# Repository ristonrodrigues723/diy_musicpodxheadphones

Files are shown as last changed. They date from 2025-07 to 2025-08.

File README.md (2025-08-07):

# diy_musicpod x headphones

DIY MusicPod x Headphones
Project Cost: $110

Hours Spent: 47 

Description:
This is an audiophile-grade music player, custom-designed by me and inspired by the Sony Walkman. I have designed an audiophile-grade MP3 player with a built-in DAC and amplifier, along with supporting headphones. Two people can use this to listen to music at the same time due to the use of dual jacks.

How to Use This Project:
u can Use it to listen to music without the distraction of ads or phone notifications. It's a seamless, audiophile-grade music experience without intrusions. The dual jacks make it easy for two people to plug in different earphones and listen to the same music.

Why did you make this project?-
I wanted an audiophile-grade music experience without the high price tag. Making something of my own was the most logical way to do it, so I designed and built this project.

Sources

onshape link(mp3player)-https://cad.onshape.com/documents/048c7b74ffe28b9d030bc2e5/w/0375e359a7d5bf4b5c1c63b7/e/c909d057c5888ffc41c2d2ab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

onshape headphone(heacdphones)-https://cad.onshape.com/documents/eff9b728d72c17e819885825/w/59bd607cd141dc798db98d86/e/9926fdbecd58d2b1f8b178f7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

| Item Name | Price (INR) | Price (USD) | Quantity | Vendor | Link |
|---|---|---|---|---|---|
| ESP32-S3 Development Board | 1500 | 17.45 | 1 | Amazon | [Link](https://www.amazon.in/OceanLabz-ESP32-S3-DevKit-N16R8-MicroPython-Unsoldered/dp/B0F9XB91XG) |
| UDA1334A I2S DAC Stereo Decoder Module | 338.66 | 3.94 | 1 | ImportDukan | [Link](https://www.importdukan.com/uda1334a-i2s-dac-stereo-decoder-module) |
| TDA1308 Headphone Amplifier Board | 107.58 | 1.25 | 1 | ImportDukan | [Link](https://www.importdukan.com/tda1308-stereo-driver-audio-module) |
| MicroSD Card Module (SPI) | 61.36 | 0.71 | 1 | ImportDukan | [Link](https://www.importdukan.com/micro-sd-card-reader-module) |
| Flat LiPo Battery (BIS Certified) | 449 | 5.22 | 1 | ThinkRobotics | [Link](https://thinkrobotics.com/products/bis-certified-3-7v-lipo-batteries?variant=40048541728854) |
| TP4056 Li-ion Charging Module (Type-C) | 85 | 1.00 | 2 | ImportDukan | [Link](https://www.importdukan.com/tp4056-1a-li-ion-lithium-battery-charging-module-with-current-protection-type-c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) |
| ST7735 TFT LCD Display Module | 400 | 4.65 | 1 | roboticsdna | [Link](https://roboticsdna.in/product/1-8-inch-tft-lcd-module-128-x-160-with-4-io-spi/) |
| Tactile Buttons 12mm | 49 | 0.57 | 7 | ImportDukan | [Link](https://www.importdukan.com/12x12x5mm-tactile-4-pin-push-button-switch) |
| 3.5mm TRS Stereo Audio Jack (Through-hole) | 50 | 0.58 | 2 | roboticsdna | [Link](https://roboticsdna.in/product/pj-307-3-5-mm-audio-jack-connector-pcb-mount-female-socket-5-pin/) |
| SPDT Switches (Right + Normal) | 40 | 0.47 | 1 | Sharvi Electronics | [Link](https://roboticsdna.in/product/slide-switch-5mm-spdt-1p2t-pack-of-10/) |
| Thin Hook-up Wires | 80 | 0.93 | 1 | Robu.in | [Link](https://robu.in/product/hook-up-wire-kit/) |
| Headers (5 pcs) | 100 | 1.16 | 1 | ImportDukan | [Link](https://www.importdukan.com/40-pin-male-header-connector-strip-breakable-right-angle-5pcs) |
| SD Card | 470 | 5.47 | 1 | Amazon.in | [Link](https://www.amazon.in/dp/B0B8GGVHPQ) |
| Custom PCB Fabrication | 1500 | 17.45 | 1 | JLCPCB/PCBWay/NextPCB | Coupon applied |
| 3D Printed Enclosure + Shipping | 501 | 5.83 | 1 | 3D Printing Service | 6 for shipping |
| Noel White Soldering Flux Paste 10gm | 18.88 | 0.22 | 1 | ImportDukan | [Link](https://www.importdukan.com/noel-white-soldering-flux-paste-10gm) |
| 10cm Male to Male Jumper Cable Wire | 18.88 | 0.22 | 1 | ImportDukan | [Link](https://www.importdukan.com/10cm_male_to_male_jumper_cable_wire_for_arduino) |
| Desoldering Wick | 59 | 0.69 | 1 | ImportDukan | [Link](https://www.importdukan.com/desoldering-wick) |
| Noel Solder Wire 60/40 10gm | 35.4 | 0.41 | 1 | ImportDukan | [Link](https://www.importdukan.com/noel-solder-wire-60-40-10gm) |
| ThinkRobotics Shipping | 100 | 1.16 | 1 | ThinkRobotics | Shipping charge |
| ImportDukan Shipping | 100 | 1.16 | 1 | ImportDukan | Shipping charge |
| Headphone Earpads Cushion | 1300 | 15.12 | 1 | Amazon | [Link](https://www.amazon.in/SoloWIT-Professional-Cooling-Gel-QuietComfort-Replacement/dp/B0B8GGVHPQ) |
| Speaker 8 OHM 40mm 2W | 280 | 3.26 | 2 | Amazon | [Link](https://www.amazon.in/gp/product/B09B2Q6G7H) |
| Battery for Headphones (800mAh) | 345 | 4.01 | 1 | Amazon | [Link](https://www.amazon.in/gp/product/B0D54MCMKC) |
| Headphone Headband | 449 | 5.22 | 1 | Amazon | [Link](https://www.amazon.in/Mizi-Headband-Cover-Audio-Technica-Replacement/dp/B0C3QZZJ99) |
| Screws 2x4.5mm | 40 | 0.47 | 1 | roboticsdna | [Link](https://roboticsdna.in/product/2-2mm-dia-9-5mm-ss-self-tapping-screw-25-pieces/) |
| Screws 2.2x9.5mm | 23 | 0.27 | 1 | roboticsdna | [Link](https://roboticsdna.in/product/2-2-x-6mm-ss-self-tapping-screw-1000-pcs/) |
| Screws 2.2x6mm | 30 | 0.35 | 1 | roboticsdna | [Link](https://roboticsdna.in/product/2-2mm-dia-9-5mm-ss-self-tapping-screw-25-pieces/) |
| Buffer for price increase / part change / unavailability | 800 | 10.00 | — | — | — |
| **Total** | **6250.16** | **110.00** | — | — | — |

diy mp3 player mp3pod-
main img

button set




schematic-


pcb-


front-

back-

 diy headphones -

  
cups



full assembly


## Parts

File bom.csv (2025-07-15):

Item Name | Price (INR) | Price (USD) | Quantity | Vendor | Link
ESP32-S3 Development Board | 1500 | 17.4496215 | 1 | amazon | https://www.amazon.in/OceanLabz-ESP32-S3-DevKit-N16R8-MicroPython-Unsoldered/dp/B0F9XB91XG?s=industrial
UDA1334A I2S DAC Stereo Decoder Module | 338.66 | 3.939659211 | 1 | ImportDukan | https://www.importdukan.com/uda1334a-i2s-dac-stereo-decoder-module (287 + 18% GST)
TDA1308 Headphone Amplifier Board | 107.58 | 1.251486854 | 1 | ImportDukan | https://www.importdukan.com/tda1308-stereo-driver-audio-module (91 + 18% GST)
MicroSD Card Module (SPI) | 61.36 | 0.7138058502 | 1 | ImportDukan | https://www.importdukan.com/micro-sd-card-reader-module (52 + 18% GST)
Flat LiPo Battery (BIS Certified) | 449 | 5.223253369 | 1 | ThinkRobotics | https://thinkrobotics.com/products/bis-certified-3-7v-lipo-batteries?variant=40048541728854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 (Price includes 80 shipping)
TP4056 Li-ion Charging Module (Type-C) | 85 | 1 | 2 | ImportDukan | https://www.importdukan.com/tp4056-1a-li-ion-lithium-battery-charging-module-with-current-protection-type-c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 (35 + 18% GST)
ST7735 TFT LCD Display Module | 400 | 4.6532324 | 1 | roboticsdna | https://roboticsdna.in/product/1-8-inch-tft-lcd-module-128-x-160-with-4-io-spi/
tactile buttons 12mm | 49 | 0.570020969 | 7 | import dukan | https://www.importdukan.com/12x12x5mm-tactile-4-pin-push-button-switch
3.5mm TRS Stereo Audio Jack (Through-hole) | 50 | 0.58165405 | 2 | robotics dna | https://roboticsdna.in/product/pj-307-3-5-mm-audio-jack-connector-pcb-mount-female-socket-5-pin/
sdpt switchdes both right and normal | 40 | 0.46532324 | 1 | Sharvi Electronics) | https://roboticsdna.in/product/slide-switch-5mm-spdt-1p2t-pack-of-10/
Thin Hook-up Wires | 80 | 0.93064648 | 1 | Robu.in) | https://robu.in/product/hook-up-wire-kit/ (or similar)
headres (mqq is 5 no ised why this is the case) | 100 | 1.1633081 | 1 | import dukan | https://www.importdukan.com/40-pin-male-header-connector-strip-breakable-right-angle-5pcs
sd card | 470 | 5.46754807 | 1 | Amazon.in) | https://www.googleadservices.com/pagead/aclk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
Custom PCB Fabrication | 1500 | 17.4496215 | 1 | PCBway/JLCPCB/NextPCB | jlc cupons
3D Printed Enclosure Shipping | 501 | 5.828173581 | 1 | 3D Printing Service | 6 for shipping
Noel White Soldering Flux Paste 10gm | 18.88 | 0.2196325693 | 1 | ImportDukan | https://www.importdukan.com/noel-white-soldering-flux-paste-10gm?search=solder&description=true&page=5 (16 + 18% GST)
10cm Male to Male Jumper Cable Wire | 18.88 | 0.2196325693 | 1 | ImportDukan | https://www.importdukan.com/10cm_male_to_male_jumper_cable_wire_for_arduino (16 + 18% GST)
Desoldering Wick | 59 | 0.686351779 | 1 | ImportDukan | https://www.importdukan.com/desoldering-wick (Assumed base 50 + 18% GST)
Noel Solder Wire 60/40 10gm | 35.4 | 0.4118110674 | 1 | ImportDukan | https://www.importdukan.com/noel-solder-wire-60-40-10gm (30 + 18% GST)
ThinkRobotics Shipping | 100 | 1.1633081 | 1 | roboticsdna | (Shipping charge for order)
ImportDukan Shipping | 100 | 1.1633081 | 1 | ImportDukan | (Shipping charge for order)
hesadphone eafpads cusions | 1300 | 15.1230053 | 1 | amazon | https://www.amazon.in/SoloWIT-Professional-Cooling-Gel-QuietComfort-Replacement/dp/B0B8GGVHPQ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
Speaker 8 OHM Trumpet - Diameter 40mm - 2 Watt | 280 | 3.25726268 | 2 | amazon | https://www.amazon.in/gp/product/B09B2Q6G7H/ref=ewc_pr_img_1?smid=A2JDRZEGU1IDE2&psc=1
bazttery for headphones 800mah | 345 | 4.013412945 | 1 | amazon | https://www.amazon.in/gp/product/B0D54MCMKC/ref=ox_sc_act_title_1?smid=A3QQB9C2QXM7ZJ&psc=1
headphone headband | 449 | 5.223253369 | 1 | amazon | https://www.amazon.in/Mizi-Headband-Cover-Audio-Technica-Replacement/dp/B0C3QZZJ99
acrews 2x4.5mm | 40 | 0.46532324 | 1 | roboticsdna | https://roboticsdna.in/product/2-2mm-dia-9-5mm-ss-self-tapping-screw-25-pieces/
screws 2.2x9.5mm | 23 | 0.267560863 | 1 | roboticsdna | https://roboticsdna.in/product/2-2-x-6mm-ss-self-tapping-screw-1000-pcs/
screws 2.2x6mm | 30 | 0.34899243 | 1 | roboticsdna | https://roboticsdna.in/product/2-2mm-dia-9-5mm-ss-self-tapping-screw-25-pieces/
buffer for price increse part change, or slae end vendor component unavailibility | 800 | 10
total | 6250.16 | 108.7306564

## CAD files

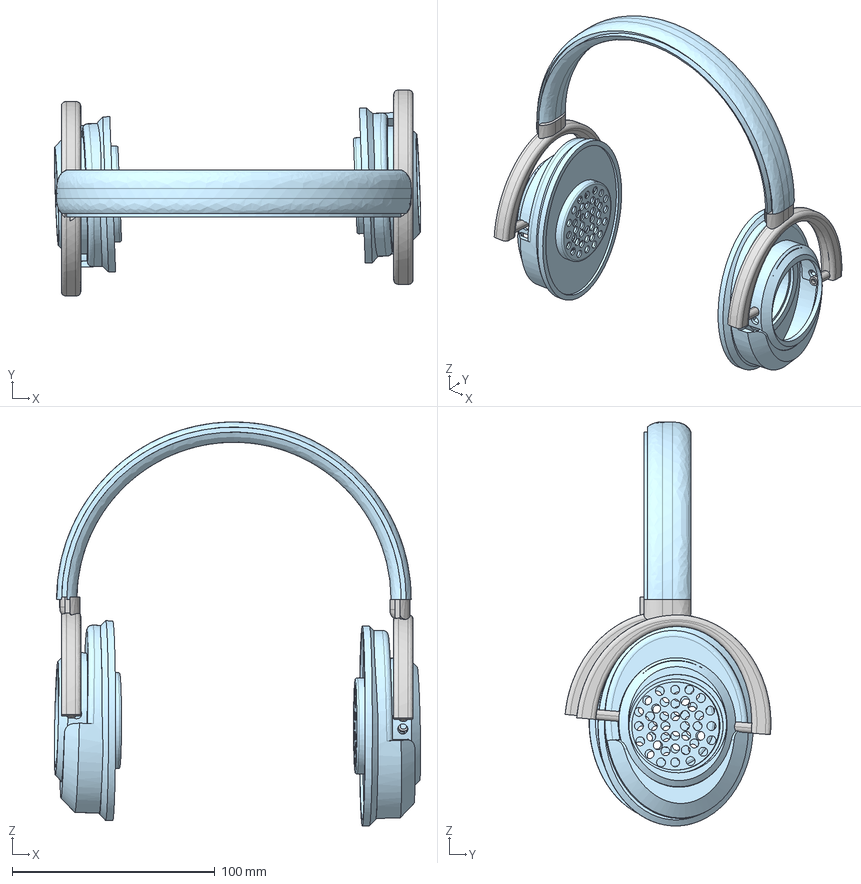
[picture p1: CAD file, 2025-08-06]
3dfies/headphone assembly1.step
180.7 x 101.6 x 199.3 mm

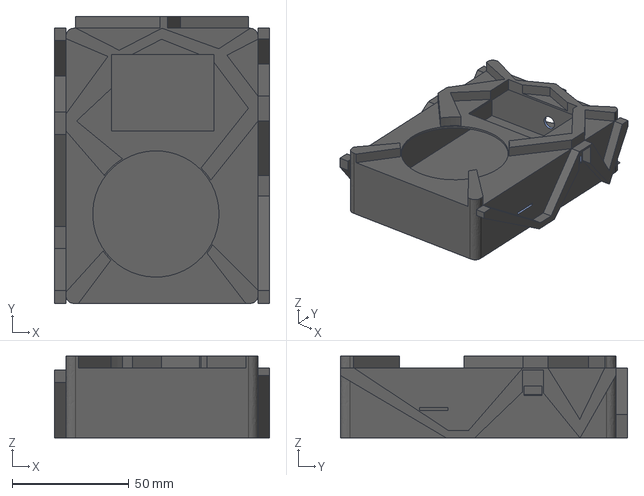
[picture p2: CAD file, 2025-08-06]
3dfies/mp3case (2).step
92.1 x 122.7 x 35.0 mm

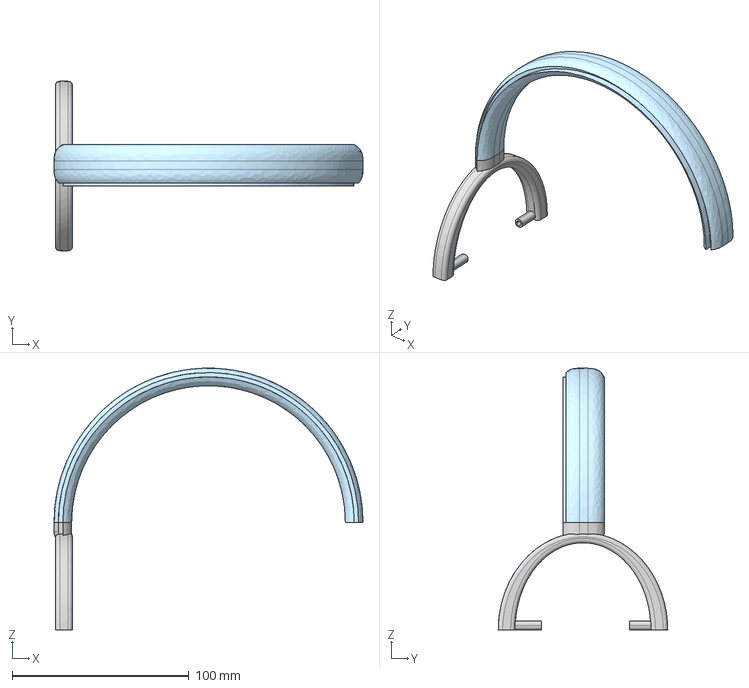
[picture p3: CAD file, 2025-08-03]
3dfies/Part Studio 1.step
175.0 x 96.0 x 148.2 mm

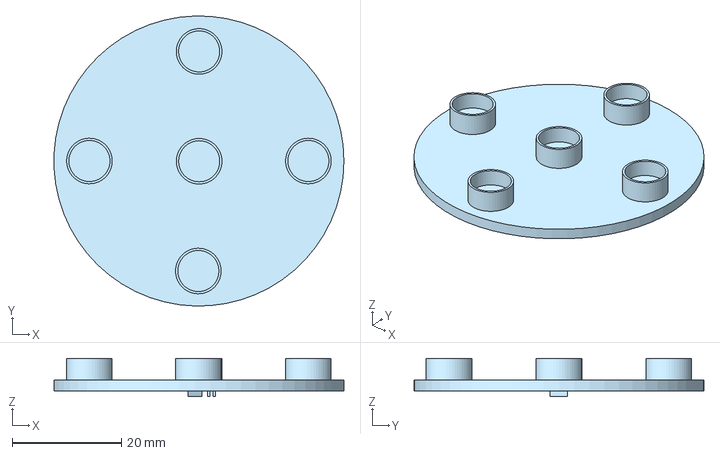
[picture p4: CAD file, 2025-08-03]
3dfies/buttons (1).step
53.0 x 53.0 x 7.00 mm

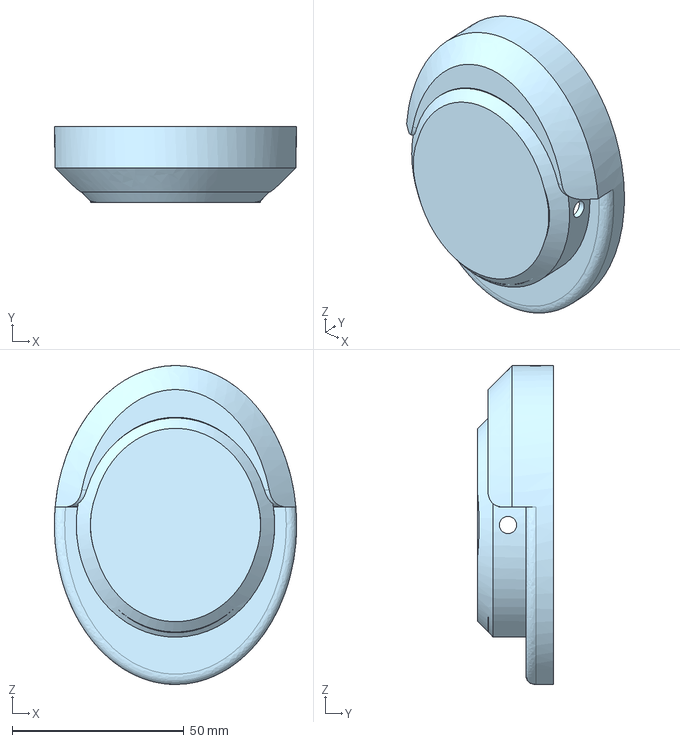
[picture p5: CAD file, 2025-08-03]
3dfies/cup(A) Copy 1.step
70.5 x 22.0 x 92.8 mm

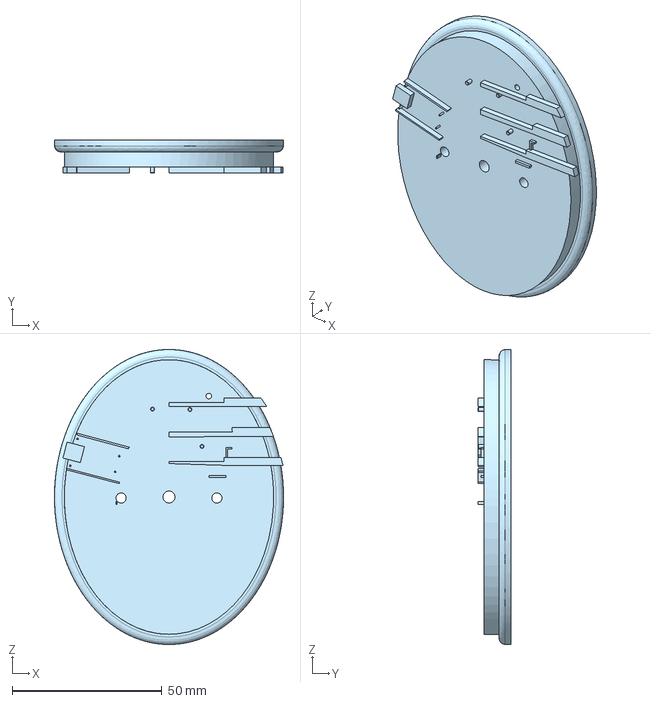
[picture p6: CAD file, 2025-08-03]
3dfies/electronics holdr part b.step
76.6 x 11.0 x 98.6 mm

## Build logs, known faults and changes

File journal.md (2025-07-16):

dtae day 7/7/25
tasks- nspeant a wek finding out the necesary components only fotr the selkles to stop selling them the country is shit basic compinents cant be found,
i recomp[ileed the entire bom this wont be a single mp3 ipod like devkice but combo of ipod/mp3 and dit headphones vreting headphones an ipod is easy getting parts in india is shit 
 tasks done today find replacements fir vendors , reserch , itrate imporve.
 man most good parts arent available in india ordering form cina sucksbigtime due to customs i personally called 3-4 vemnmdos but most refused intlkl cards this pushes up the budget not a single ve\ndor has most parts mos have 2-3 so it adds upo the cost for dilevery without thise parts nothing would be good. i crerated and revised the bom it should work for now atleast

- started with scheatic i cant not add the boster module itll make tyhe ipos more cluncky no more compact but tgia wont work without it
- 
- 
 just do tiring the pins are getting mesed uop

finished buton one are remaining

 still require a lot of fixes

 time spent todaY-8 hrs

 day 2 8/7/25
 tasks 
 rewired the esp and the dac needed had to spent an entire our as i refered the wrong datasheet 
 ok it was a problem with thte netlist not updating nas qfrequently as need this caused complete vcaos fro th last 1.5 hrs its good to go now cirut was righr nee to addn the 5 switches for control
shouod do the task if not il have to revixse after wiring
finall;y 
the pcb still to muvch cosgulated man ill become mad before i make it compact

 man putting elements at top and bottommmesses things up
 migrated everything to easyeda pro now it seems good-
 
 found code actual working codwe that can be adapted good news man
routing sucks big time tried the  components are bith side of pcb and adnjustig them is a headache making it compavrt is more of a headache
managed to make it compact finally found the error



fixed last wirinf thatgo stuck cotinuously



 time pent 8-hr.
day 3 9/7/25
had to add comon gend for the tp charger module

things got messed the vendor droped support for hcb found another thaTs cheaper so lets see where it goes
some pins got messed up sck and button io got connected togethrrer shorting the circut had to compeletely reset the circut
damn somehow no matter what i do the netlist isnt updating iy can lead to problems kater
made it as compact as i could without pcba
man still error not fixed schematic done its connected but somehow pchb isnt getting chaNGED maybeil have to reroute

there were 3 routings betwween pin 17 31 of esp anf button and dac allmwere connected in pcb despite cghanges in schenatic routing didnt help re routed and al errors gone will check netlist again
finally no errpor 





fixed the pcb no drc errors no footpront erros footprints were wrong that was causing mismatch betee schematic and pch fixed manually routed and done did eith mofel too next stdep case im not surd if this wil be done swithin time frame i nwnt to procced with with headphones but they wont be compeketed within this timeframe

time speamnt 8 hrs

day 4 
binded all 3de models from easy eda serch and fixing them was a headache man.




created case base top extrudes and othe r manirs still 3cm height not comoact at ill in can tryb2 but needc pcb to actually bporoceed further

hrs -4

day5,6
tasks done- created the 3d model, gave more time fixed the isue with jack sd card and the charging port slot


added the main button ring spenat 3 hrs here it was a headche it got messed had to get real dimens iterate til i could get it riht


wanted to c rrste the set of hradphones from scratch but parts as i wantt are not available in india and alibaba is dievering so ill use old pcb from old headphone as the brain








finally got thr slot for carging right 2 extruses 2 deletions laTER


finished the button slidinfg btutto ttio turn it on off like ipod ill later makr it more compact once oarts arrive

got the code fro t]github addeed minor changes code isnt even mine i made my right oinallocations and adde buton functionality fromm a yt vid - little help 

total time -8 hrs 

date -14/7/25
tasks done - reserched all needed things for headphone more reserch, found out old pcb stil works wil need a battery headphone pads ill design the case, started basic design

SoloWIT Professional Cooling-Gel Earpads for Bose QuietComfort 35 (QC35) and Quiet Comfort 35 II (QC35 II) Over-Ear Headphones, Ear Pads Cushions Replacement with Noise Isolation Foam wil be used as earpads




done with headband its 15.5 cm wide so most human heads will fit in done with appropraiate illets and stuff








time spent 4 hrs

day -15/7/25
tasks experimenting with the arc and ellipse too to cereaRE earpad body-









finished speaker holder 



founf out i cant se spakers form omy old headphoes reserched andd aded neede spaekers and battey to bom the pcb is working had to solcs to a speraker and bafrtery yto trstg now il compekete this by tommorow





totral time today-4.5 hrs

day 16/7/.25


created middle part b to hold modt nedded stuff
eaercusion chamfer


midddle part to hold imp stuff



imprted thr tp4050 convert4d stp to stl moe creaing holders for that



time spemt-6 hrs

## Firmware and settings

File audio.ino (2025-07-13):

//this code is taken from github just made my pin allocatio + minor buton changes original code didnt allow some functions examples are found on github repos and yt vids
// code source-https://github.com/schreibfaul1/ESP32-audioI2S
#include "Arduino.h"
#include "WiFi.h"         // For internet acess if needs
#include "Audio.h"        // The ESP32-audioI2S library
#include "SD.h"           // For SD card access
#include "FS.h"           // For file system access
#include <vector>         // For dynamic song list
#include <Adafruit_GFX.h> // Core graphics library
#include <Adafruit_ST7735.h> // ST7735 TFT library

// I2S Audio Pins (from U4 UDA1334A(this iss the dac module if ur in us ull need to use ur dac poins) )
#define I2S_DOUT      31
#define I2S_BCLK      40
#define I2S_LRC       41

// SD Card Pins (from U9 SD CARD READER in pcb the spi ardon reader)
#define SD_CS         35
#define SPI_MOSI      36 // Shared with TFT_SDA
#define SPI_MISO      38
#define SPI_SCK       37 // Shared with TFT_SCK

// TFT Display Pins (from D1 1.8 INCH TFT DISPLAY ST7735 from robocraze that im planning to buy)
#define TFT_CS        4
#define TFT_DC        6
#define TFT_RST       5

// Button Pins (from U10, U11, U12, U13, U14 buttons)
#define BUTTON_CENTER 15 // center btn
#define BUTTON_UP     16 // up btn
#define BUTTON_DOWN   17 // dn btn
#define BUTTON_RIGHT  18 // right btn
#define BUTTON_LEFT   19 // left btn

// --- Global Objects ---
Audio audio;
Adafruit_ST7735 tft = Adafruit_ST7735(TFT_CS, TFT_DC, SPI_MOSI, SPI_SCK, TFT_RST);

// --- Button Handling Variables ---
const int BUTTON_PINS[] = {BUTTON_CENTER, BUTTON_LEFT, BUTTON_RIGHT, BUTTON_UP, BUTTON_DOWN};
const int NUM_BUTTONS = sizeof(BUTTON_PINS) / sizeof(BUTTON_PINS[0]);

unsigned long lastDebounceTime[NUM_BUTTONS] = {0}; //check Last time whn button state changed
int buttonState[NUM_BUTTONS] = {HIGH};
int lastButtonState[NUM_BUTTONS] = {HIGH};

// Removed pressStartTime, isLongPress, clickCount, lastClickTime
// since we are simplifying button logic to only single presses initially.

const unsigned long DEBOUNCE_DELAY = 50;
// Removed DOUBLE_CLICK_TIME and LONG_PRESS_TIME

// --- Playback and Menu State Variables ---
enum PlaybackState {
    PAUSED,
    PLAYING
};
PlaybackState currentPlaybackState = PAUSED;

enum MenuState {
    MAIN_PLAYBACK_SCREEN,
    PLAYLIST_BROWSE_SCREEN
};
MenuState currentMenuState = MAIN_PLAYBACK_SCREEN;

String currentSongPath = "";
int currentSongIndex = -1;
std::vector<String> songList; //song paTHS on card are stored here
int menuSelectedItem = 0;


int currentVolume = 12; //default vol

void scanMusicFiles();
void playSong(String path);
void adjustVolume(int newVolume);
void updateTFTDisplay();
void handleButtons();
void processButtonEvent(int buttonIndex); // Simplified: no doubleClick/longPress args

// Audio Callback Functions (ESP32-audioI2S example on the https://github.com/schreibfaul1/ESP32-audioI2S)
void audio_info(const char *info);
void audio_id3data(const char *info);
void audio_eof_mp3(const char *info);
void audio_showstation(const char *info);
void audio_showstreamtitle(const char *info);
void audio_bitrate(const char *info);
void audio_commercial(const char *info);
void audio_icyurl(const char *info);
void audio_lasthost(const char *info);
void audio_eof_speech(const char *info);

// --- Setup Function ---
void setup() {
    Serial.begin(115200);
    Serial.println("Starting ESP32 Audio Player...");

    // Initializes SPI for SD card and TFT
    SPI.begin(SPI_SCK, SPI_MISO, SPI_MOSI);

    // Initialize SD card
    pinMode(SD_CS, OUTPUT);
    digitalWrite(SD_CS, HIGH); // SD card CS hih
 //when not neing used
  if (!SD.begin(SD_CS)) {
        Serial.println("SD Card Mount Failed");
        tft.fillScreen(ST7735_BLACK);
        tft.setCursor(0, 0);
        tft.setTextColor(ST7735_RED);
        tft.println("SD ERROR!");
        delay(3000);
        // lop for re apen,to
    } else {
        Serial.println("SD Card Initialized");
    }

    // Initializes TFT
    tft.initR(INITR_18GREENTAB);
    tft.setRotation(1);
    tft.fillScreen(ST7735_BLACK);
    tft.setTextWrap(false);
    tft.setTextSize(1);
    tft.setTextColor(ST7735_WHITE);
    tft.setCursor(0, 0);
    tft.println("Initializing Audio...");


    for (int i = 0; i < NUM_BUTTONS; i++) {
        pinMode(BUTTON_PINS[i], INPUT_PULLUP);
    }


    audio.setPinout(I2S_BCLK, I2S_LRC, I2S_DOUT);
    audio.setVolume(currentVolume);

    // Scan for music files on SD card
    scanMusicFiles();

    updateTFTDisplay(); // Initial display
}

// --- Main Loop ---
void loop() {
    audio.loop();      // Keep the audio library running
    handleButtons();    // Check for button presses and execute actions
    vTaskDelay(1);      // Yield to other tasks
}

// --- Helper Functions ---

void scanMusicFiles() {
    songList.clear(); // Clear existing list
    Serial.println("Scanning SD card for audio files...");

    File root = SD.open("/");
    if (!root) {
        Serial.println("Failed to open root directory.");
        return;
    }

    File file = root.openNextFile();
    while (file) {
        if (!file.isDirectory()) {
            String fileName = file.name();
            // Basic check for common audio file extensions
            if (fileName.endsWith(".mp3") || fileName.endsWith(".wav") ||
                fileName.endsWith(".flac") || fileName.endsWith(".m4a") ||
                fileName.endsWith(".ogg") || fileName.endsWith(".opus") ||
                fileName.endsWith(".aac")) {
                songList.push_back("/" + fileName); // Store full path
            }
        }
        file = root.openNextFile();
    }
    root.close();

    if (songList.empty()) {
        Serial.println("No supported audio files found on SD card.");
    } else {
        Serial.print("Found ");
        Serial.print(songList.size());
        Serial.println(" audio files.");
    }
}

void playSong(String path) {
    if (path == currentSongPath && currentPlaybackState == PLAYING) {
        // Already playing this song, do nothing
        return;
    }
    Serial.print("Playing: ");
    Serial.println(path);
    audio.stop(); // Stop current playback if any
    audio.connecttoFS(SD, path.c_str());
    currentSongPath = path;
    currentPlaybackState = PLAYING;
    updateTFTDisplay(); // Update display immediately
}

void adjustVolume(int newVolume) {
    if (newVolume < 0) newVolume = 0;
    if (newVolume > 21) newVolume = 21; // Max volume  ony alow for library
    currentVolume = newVolume;
    audio.setVolume(currentVolume);
    Serial.print("Volume set to: ");
    Serial.println(currentVolume);
    updateTFTDisplay(); // Updat display
}

// This function manages the different display states
void updateTFTDisplay() {
    tft.fillScreen(ST7735_BLACK); // Clears te screen

    switch (currentMenuState) {
        case MAIN_PLAYBACK_SCREEN: {
            tft.setCursor(0, 0);
            tft.setTextColor(ST7735_CYAN);
            tft.println("Now Playing:");

            tft.setTextColor(ST7735_WHITE);
            String displaySongName = "No song selected.";
            if (currentSongPath != "") {
                int lastSlash = currentSongPath.lastIndexOf('/');
                displaySongName = currentSongPath.substring(lastSlash + 1);
            }
            // Display song name, potentially truncate if too long
            if (displaySongName.length() > 20) { // Adjust based on your font size and screen width
                displaySongName = displaySongName.substring(0, 17) + "...";
            }
            tft.setCursor(0, 16);
            tft.println(displaySongName);

            tft.setCursor(0, 40);
            tft.setTextColor(ST7735_GREEN);
            tft.print("Volume: ");
            tft.println(currentVolume);

            tft.setCursor(0, 56);
            tft.setTextColor(ST7735_YELLOW);
            tft.print("Status: ");
            if (currentPlaybackState == PLAYING) {
                tft.println("Playing");
            } else {
                tft.println("Paused");
            }
            tft.setCursor(0, 80);
            tft.setTextColor(ST7735_MAGENTA);
         tft.println("C: Play/Pause/List");
               tft.println("R/L: Next/Prev");
             tft.println("U/D: Vol +/-");
            tft.println(""); 
            break;
        }

           case PLAYLIST_BROWSE_SCREEN: {
            tft.setCursor(0, 0);
            tft.setTextColor(ST7735_CYAN);
            tft.println("Playlist:");
            int maxItemsOnScreen = (tft.height() - 20) / 10;
            int displayStartIdx = max(0, menuSelectedItem - maxItemsOnScreen / 2);
            int displayEndIdx = min((int)songList.size() - 1, displayStartIdx + maxItemsOnScreen - 1);

            if (displayEndIdx - displayStartIdx + 1 < maxItemsOnScreen) {
                displayStartIdx = max(0, displayEndIdx - maxItemsOnScreen + 1);
            }

            for (int i = displayStartIdx; i <= displayEndIdx; ++i) {
                String displayName = songList[i];
                int lastSlash = displayName.lastIndexOf('/');
                displayName = displayName.substring(lastSlash + 1);

  
                if (displayName.length() > 20) {
                    displayName = displayName.substring(0, 17) + "...";
                }

                tft.setCursor(0, 16 + (i - displayStartIdx) * 10);
                if (i == menuSelectedItem) {
                    tft.setTextColor(ST7735_YELLOW); 
                    tft.print("> "); 
                } else {
                    tft.setTextColor(ST7735_WHITE);
                    tft.print("  "); 
                }
                tft.println(displayName);
            }

            // If playlist is empty
         if (songList.empty()) {
                tft.setTextColor(ST7735_RED);
                      tft.setCursor(0, 16);
                tft.println("No songs found!");
            }


            tft.setCursor(0, tft.height() - 20)
            tft.setTextColor(ST7735_MAGENTA);
           tft.println("C: Select/Back"); 
       tft.println("U/D: Scroll");
               break;
        }
    }
}

void handleButtons() {
    unsigned long currentTime = millis();

    for (int i = 0; i < NUM_BUTTONS; i++) {
        int reading = digitalRead(BUTTON_PINS[i]);


        if (reading != lastButtonState[i]) {
            lastDebounceTime[i] = currentTime;
        }

      if ((currentTime - lastDebounceTime[i]) > DEBOUNCE_DELAY) {
            if (reading != buttonState[i]) {
                buttonState[i] = reading;

                if (buttonState[i] == LOW) { 
                    processButtonEvent(i); /
                }
            }
        }
        lastButtonState[i] = reading; // Update s last stae
    }

}

// --- Simplified processButtonEvent ---
void processButtonEvent(int buttonIndex) {
    Serial.print("Button ");
    Serial.print(BUTTON_PINS[buttonIndex]);
    Serial.print(" (Index: "); Serial.print(buttonIndex); Serial.print(")");
    Serial.println(" Pressed!"); 

    switch (currentMenuState) {
        case MAIN_PLAYBACK_SCREEN:
            if (buttonIndex == 0) { // Center Button
               
                if (currentPlaybackState == PLAYING || currentSongPath != "") { 
                    audio.pauseResume();
                    currentPlaybackState = (currentPlaybackState == PLAYING) ? PAUSED : PLAYING;
                    Serial.print("Playback: "); Serial.println(currentPlaybackState == PLAYING ? "Playing" : "Paused");
                } else { 
                    currentMenuState = PLAYLIST_BROWSE_SCREEN;
                    menuSelectedItem = currentSongIndex; // Start playlist view at current song
                    Serial.println("Center Button: To Playlist Browse");
                }
            } else if (buttonIndex == 1) { // Left Button (Previous song go t )
                if (!songList.empty()) {
                    currentSongIndex = (currentSongIndex - 1 + songList.size()) % songList.size();
                    playSong(songList[currentSongIndex]);
                }
            } else if (buttonIndex == 2) { // Right Button (Next song plays)
                if (!songList.empty()) {
                    currentSongIndex = (currentSongIndex + 1) % songList.size();
                    playSong(songList[currentSongIndex]);
                }
            } else if (buttonIndex == 3) { // Up Button (inc vol- Up)
                adjustVolume(currentVolume + 1); // Simple +1 volume
            } else if (buttonIndex == 4) { // Down Button (decreases Volume)
                adjustVolume(currentVolume - 1); 
            }
            break;

        case PLAYLIST_BROWSE_SCREEN:
            if (buttonIndex == 0) { // Center Button
          
                if (!songList.empty() && menuSelectedItem >= 0 && menuSelectedItem < songList.size()) {
                    currentSongIndex = menuSelectedItem;
                    playSong(songList[currentSongIndex]);
                    currentMenuState = MAIN_PLAYBACK_SCREEN; 
                    Serial.print("Center Button: Play song index "); Serial.println(currentSongIndex);
            } else {
                    currentMenuState = MAIN_PLAYBACK_SCREEN;
                    Serial.println("Center Button: Back to Main Playback (no selection or empty list)");
                }
          } else if (buttonIndex == 1) {
                currentMenuState = MAIN_PLAYBACK_SCREEN;
                Serial.println("Left Button: Back to Main Playback");
        } else if (buttonIndex == 2) { // Right Button

                Serial.println("Right Button: No action in Playlist Browse (currently)");
            } else if (buttonIndex == 3) { // Up Button (Scrolls up)
                if (menuSelectedItem > 0) {
                    menuSelectedItem--;
                    Serial.print("Playlist: Selected index "); Serial.println(menuSelectedItem);
                }
            } else if (buttonIndex == 4) { 
                if (menuSelectedItem < songList.size() - 1) {
                    menuSelectedItem++;
                    Serial.print("Playlist: Selected index "); Serial.println(menuSelectedItem);
                }
            }
            break;


    }
    updateTFTDisplay(); 
}

// --- Audio Callback Functions  ---
void audio_info(const char *info) {
    Serial.print("info        ");
    Serial.println(info);

}

void audio_id3data(const char *info) { //deqals with metadata
    Serial.print("id3data     ");
    Serial.println(info);
    // Update song info on scren
}

void audio_eof_mp3(const char *info) {
    Serial.print("eof_mp3     ");
    Serial.println(info);
    // Auto-pplays next song if its there in sd card
    if (currentSongIndex != -1 && !songList.empty()) {
        currentSongIndex = (currentSongIndex + 1) % songList.size();
        playSong(songList[currentSongIndex]);
    } else {
        currentPlaybackState = PAUSED; 
        updateTFTDisplay();
    }
}

void audio_showstation(const char *info) {
    Serial.print("station     ");
    Serial.println(info);
}

void audio_showstreamtitle(const char *info) {
    Serial.print("streamtitle ");
    Serial.println(info);
}

void audio_bitrate(const char *info) {
    Serial.print("bitrate     ");
    Serial.println(info);
}

void audio_commercial(const char *info) { 
    Serial.print("commercial  ");
    Serial.println(info);
}

void audio_icyurl(const char *info) { //homepage will take me to it
    Serial.print("icyurl      ");
    Serial.println(info);
}

void audio_lasthost(const char *info) { 
    Serial.print("lasthost    ");
    Serial.println(info);
}

void audio_eof_speech(const char *info) {
    Serial.print("eof_speech  ");
    Serial.println(info);
}

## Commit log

2025-07-13 Update Bom - Sheet1.csv
    [Bom - Sheet1.csv]
2025-07-15 Update and rename musicpod - Sheet1.csv to bom.csv
    [bom.csv]
2025-08-06 Rename Assembly 1.step to headphone assembly1.step
    [headphone assembly1.step]
